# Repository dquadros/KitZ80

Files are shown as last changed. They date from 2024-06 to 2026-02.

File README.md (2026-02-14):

# Kit Z80

 Este projeto tem como partida uma solicitação de um dos leitores do meu blog ([https://dqsoft.blogspot.com](https://youtube.com/@DQSoft)). Ele possui um kit dos anos 80, o CEDM-80, e gostaria de um firmware novo para ele.
 
 Para escrever o firmware o primeiro passo é ter o hardware e aí está o projeto: construir um microcomputador compatível com o CEDM-80 (versão 1, para ser mais preciso). É um projeto de médio a longo prazo, ficarei muito feliz se o concluir até a ~~metade do ano atual (2024)~~ o final do primeiro trimestre de 2026.
 
 O projeto está sendo documentado no blog e no meu canal no Youtube ([https://youtube.com/@DQSoft](https://youtube.com/@DQSoft))
 
 ## Testes do Circuito de Reset (02/06/24)
 
 Em Circuito/TesteReset está o esquema do circuito montado para testar três opções para o Reset.
 
 ## Teste do Uso do 74HC373 como Latch/Porta de Saída (13/06/24)
 
 Em Circuito/Teste373 está o esquema do circuito montado para testar o uso do 74HC373 como porta de saída.
 
 Em Programas/TstBlink está o programa usado no teste.
  
 ## Teste da  RAM (24/08/24)
 
 Em Programas/MTest está o programa, que usa o gerador de números pseudo-aleatorios do Pitfall para testar a memória RAM!
 
 ## Teste Inicial do Display (14/04/25)
 
 Com a montagem da placa de I/O iniciada, é hora de testar o circuito de acionamento do display e validar o valor dos resistores de limitação de corrente.
 
 O programa de testes está em Programas/TstDisp.
 
 ## Teste Final do Display (14/02/25)
 
 Após mais uma longa pausa, a montagem do circuito do display está completa.
 
 O programa de testes está em Programas/TstDisp.

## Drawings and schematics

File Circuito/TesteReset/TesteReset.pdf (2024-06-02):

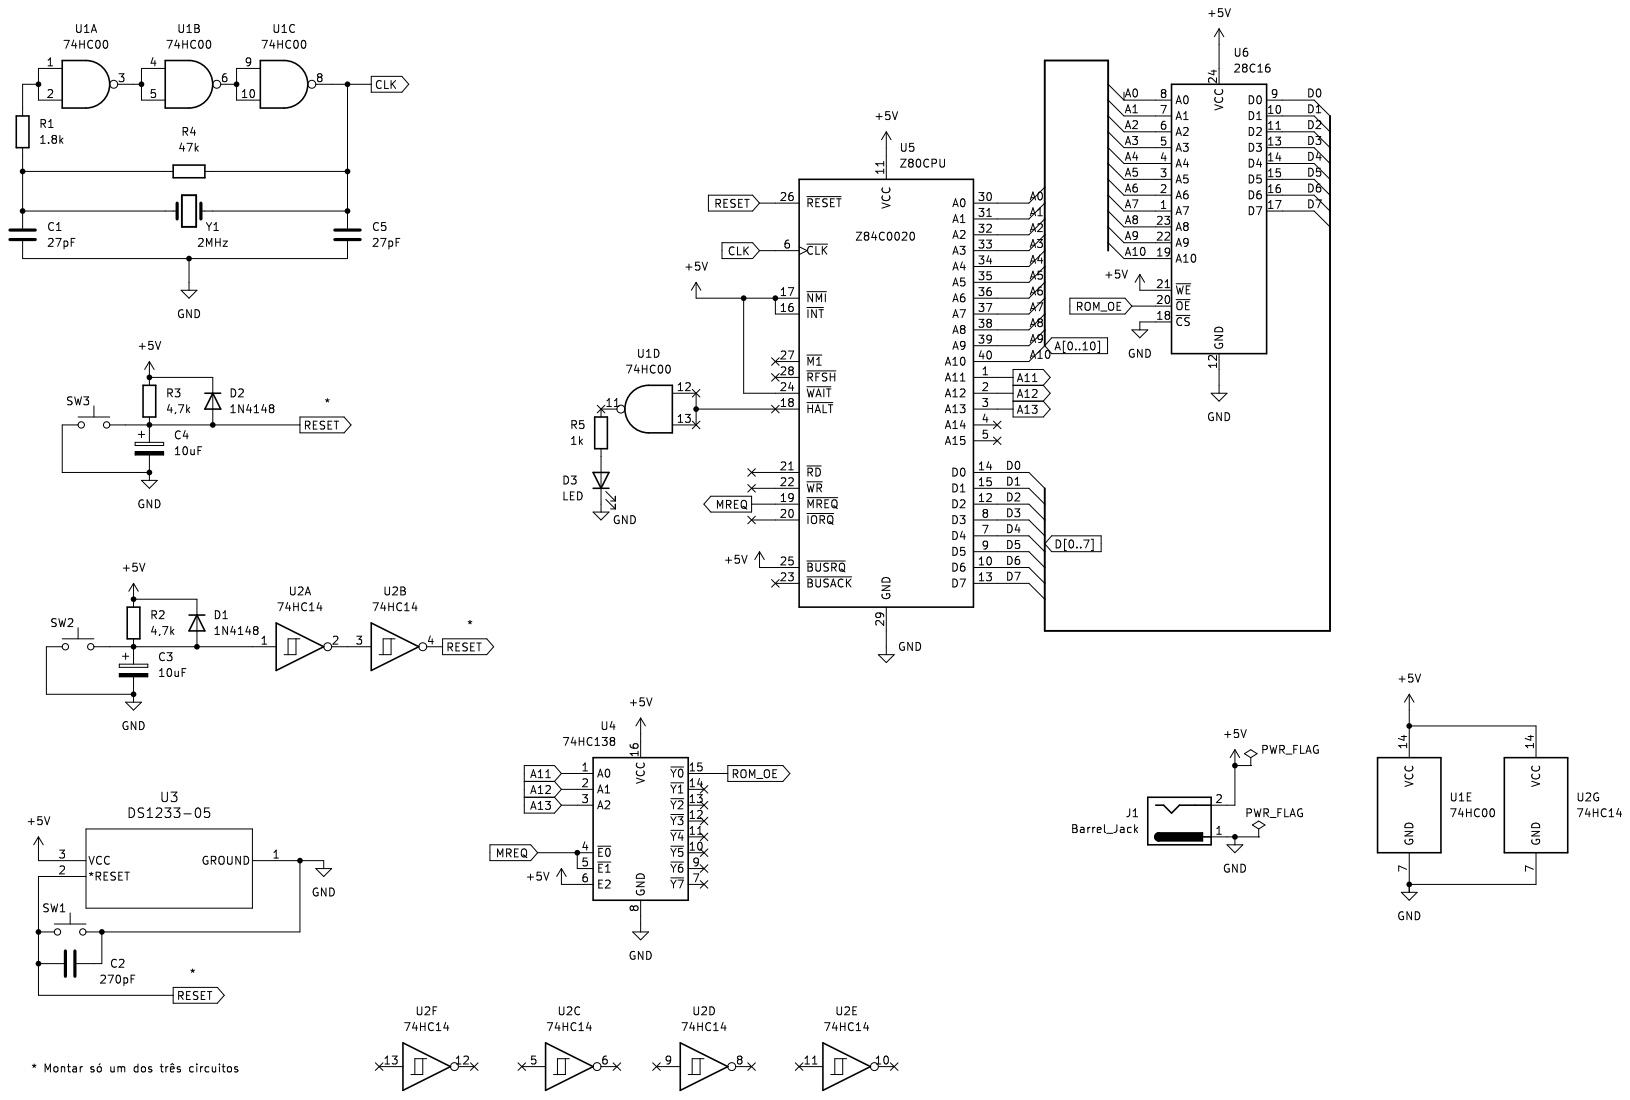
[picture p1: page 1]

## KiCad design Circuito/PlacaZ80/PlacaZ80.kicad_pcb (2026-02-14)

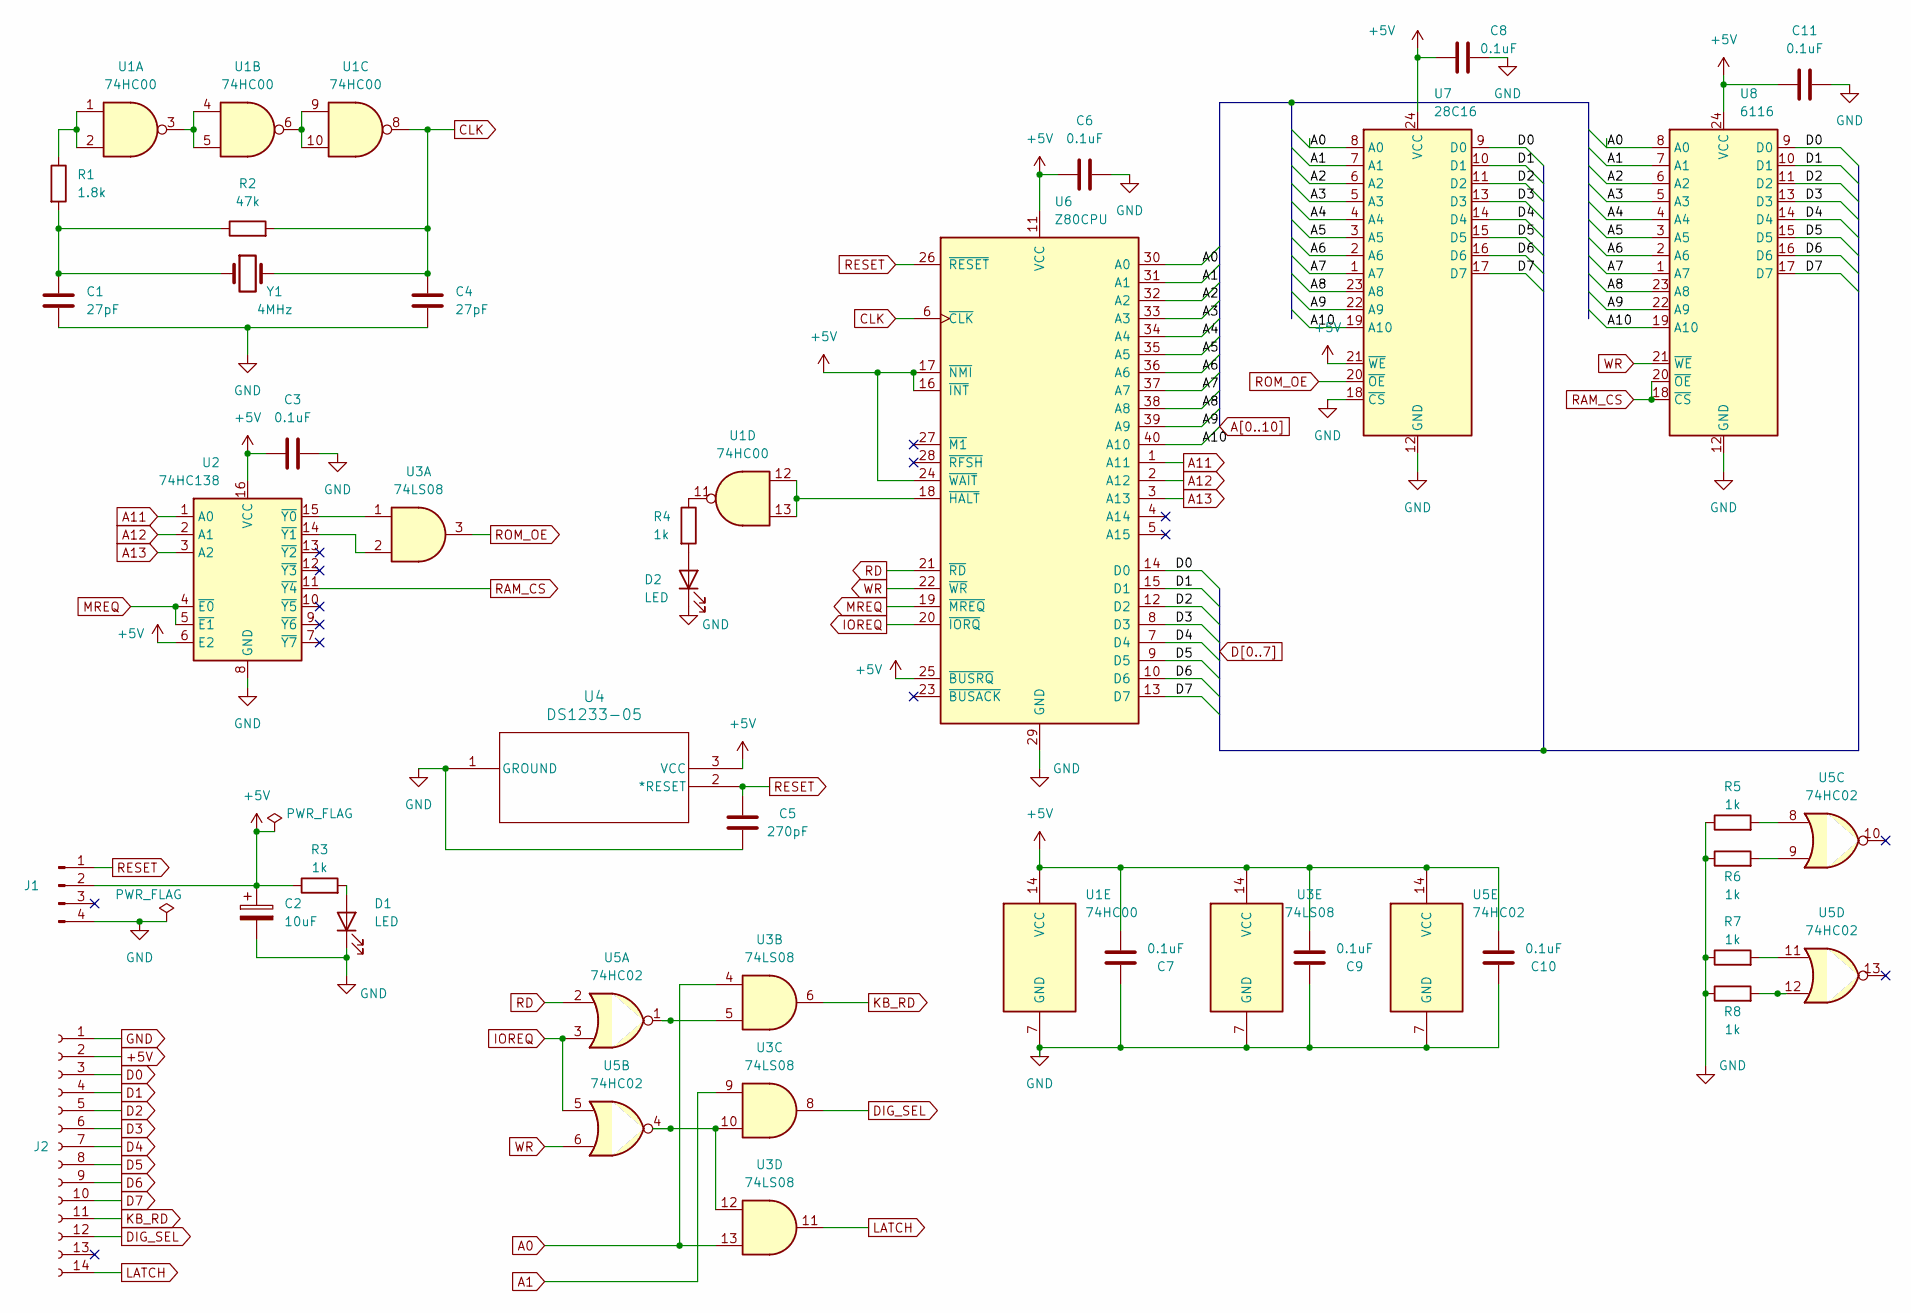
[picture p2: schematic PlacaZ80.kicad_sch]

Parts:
C1, C4: 27pF; C_Disc_D3.0mm_W2.0mm_P2.50mm
C2: 10uF; C_Radial_D5.0mm_H5.0mm_P2.00mm
C3, C6, C7, C8, C9, C10, C11: 0.1uF; C_Disc_D3.0mm_W2.0mm_P2.50mm
C5: 270pF; C_Disc_D3.0mm_W2.0mm_P2.50mm
D1, D2: LED; LED_D3.0mm
J1: Conn_01x04_Pin; PinHeader_1x04_P2.54mm_Horizontal
J2: Conn_01x14_Socket; PinSocket_1x14_P2.54mm_Horizontal
R1: 1.8k; R_Axial_DIN0207_L6.3mm_D2.5mm_P10.16mm_Horizontal
R2: 47k; R_Axial_DIN0207_L6.3mm_D2.5mm_P10.16mm_Horizontal
R3, R4, R5, R6, R7, R8: 1k; R_Axial_DIN0207_L6.3mm_D2.5mm_P10.16mm_Horizontal
U1: 74HC00; DIP-14_W7.62mm
U2: 74HC138; DIP-16_W7.62mm
U3: 74LS08; DIP-14_W7.62mm
U4: DS1233-05; 21-0250B_MXM
U5: 74HC02; DIP-14_W7.62mm
U6: Z80CPU; DIP-40_W15.24mm_Socket
U7: 28C16; DIP_Socket-24_W11.9_W12.7_W15.24_W17.78_W18.5_3M_224-1275-0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
U8: 6116; DIP-24_W15.24mm_Socket
Y1: 4MHz; Crystal_HC49-U_Vertical

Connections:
+5V: C2.1, C3.1, C6.1, C7.1, C8.1, C9.1, C10.1, C11.1, J1.2, J2.2, R3.1, U1.14 (VCC), U2.6 (E2), U2.16 (VCC), U3.14 (VCC), U4.3 (VCC), U5.14 (VCC), U6.11 (VCC), U6.16 (~INT), U6.17 (~NMI), U6.24 (~WAIT), U6.25 (~BUSRQ), U7.21 (~WE), U7.24 (VCC), U8.24 (VCC)
A0: U3.4, U3.13, U6.30 (A0), U7.8 (A0), U8.8 (A0)
A1: U3.9, U6.31 (A1), U7.7 (A1), U8.7 (A1)
A2: U6.32 (A2), U7.6 (A2), U8.6 (A2)
A3: U6.33 (A3), U7.5 (A3), U8.5 (A3)
A4: U6.34 (A4), U7.4 (A4), U8.4 (A4)
A5: U6.35 (A5), U7.3 (A5), U8.3 (A5)
A6: U6.36 (A6), U7.2 (A6), U8.2 (A6)
A7: U6.37 (A7), U7.1 (A7), U8.1 (A7)
A8: U6.38 (A8), U7.23 (A8), U8.23 (A8)
A9: U6.39 (A9), U7.22 (A9), U8.22 (A9)
A10: U6.40 (A10), U7.19 (A10), U8.19 (A10)
A11: U2.1 (A0), U6.1 (A11)
A12: U2.2 (A1), U6.2 (A12)
A13: U2.3 (A2), U6.3 (A13)
CLK: C4.1, R2.2, U1.8, U6.6 (~CLK), Y1.2
D0: J2.3, U6.14 (D0), U7.9 (D0), U8.9 (D0)
D1: J2.4, U6.15 (D1), U7.10 (D1), U8.10 (D1)
D2: J2.5, U6.12 (D2), U7.11 (D2), U8.11 (D2)
D3: J2.6, U6.8 (D3), U7.13 (D3), U8.13 (D3)
D4: J2.7, U6.7 (D4), U7.14 (D4), U8.14 (D4)
D5: J2.8, U6.9 (D5), U7.15 (D5), U8.15 (D5)
D6: J2.9, U6.10 (D6), U7.16 (D6), U8.16 (D6)
D7: J2.10, U6.13 (D7), U7.17 (D7), U8.17 (D7)
DIG_SEL: J2.12, U3.8
GND: C1.2, C2.2, C3.2, C4.2, C5.2, C6.2, C7.2, C8.2, C9.2, C10.2, C11.2, D1.1 (K), D2.1 (K), J1.4, J2.1, R5.1, R6.1, R7.1, R8.1, U1.7 (GND), U2.8 (GND), U3.7 (GND), U4.1 (GROUND), U5.7 (GND), U6.29 (GND), U7.12 (GND), U7.18 (~CS), U8.12 (GND)
IOREQ: U5.3, U5.5, U6.20 (~IORQ)
KB_RD: J2.11, U3.6
LATCH: J2.14, U3.11
MREQ: U2.4 (~E0), U2.5 (~E1), U6.19 (~MREQ)
unnamed: C1.1, R1.2, R2.1, Y1.1
unnamed: D1.2 (A), R3.2
unnamed: D2.2 (A), R4.2
unnamed: R1.1, U1.1, U1.2
unnamed: R4.1, U1.11
unnamed: R5.2, U5.8
unnamed: R6.2, U5.9
unnamed: R7.2, U5.11
unnamed: R8.2, U5.12
unnamed: U1.3, U1.4, U1.5
unnamed: U1.6, U1.9, U1.10
unnamed: U2.15 (~Y0), U3.1
unnamed: U2.14 (~Y1), U3.2
unnamed: U3.5, U5.1
unnamed: U3.10, U3.12, U5.4
unnamed: U1.12, U1.13, U6.18 (~HALT)
RAM_CS: U2.11 (~Y4), U8.18 (~CS), U8.20 (~OE)
RD: U5.2, U6.21 (~RD)
RESET: C5.1, J1.1, U4.2 (*RESET), U6.26 (~RESET)
ROM_OE: U3.3, U7.20 (~OE)
WR: U5.6, U6.22 (~WR), U8.21 (~WE)

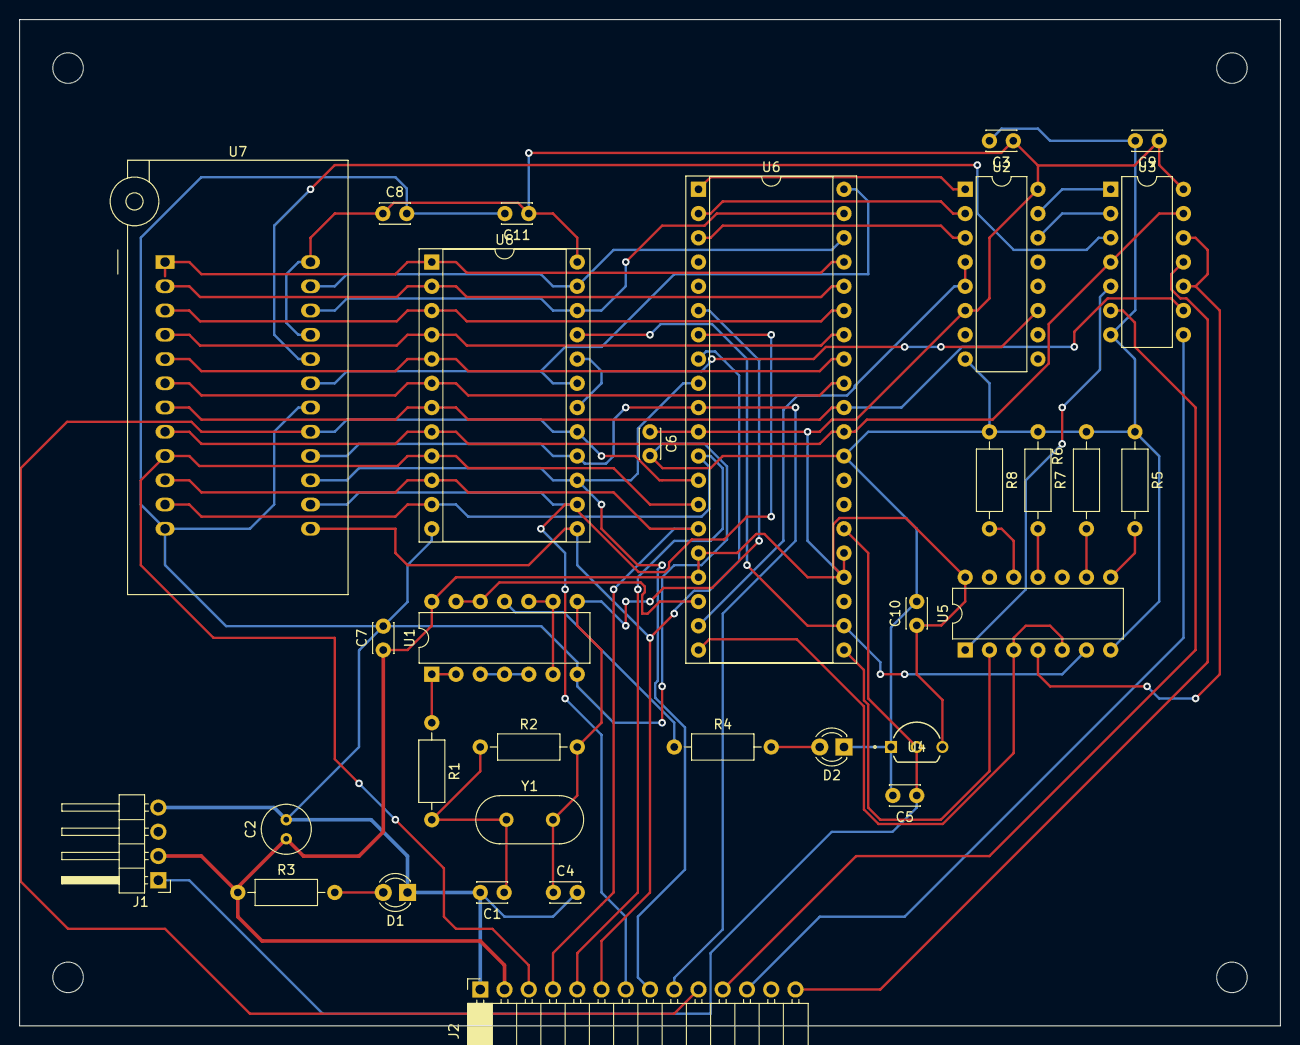
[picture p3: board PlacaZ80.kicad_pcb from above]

Board: 2 copper layers, 132.1 x 105.4 mm, 32 parts (0 on the bottom side), 51 nets.

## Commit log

2024-06-02 Inclusão do circuito de reset
    [TesteReset.kicad_sch]
2024-06-13 Acrescentado teste do 74HC373
    [Teste373.kicad_sch]
2024-08-26 Montagem e teste da placa CPU
    [PlacaZ80.kicad_pcb, PlacaZ80.kicad_sch, TesteReset.kicad_sch]
2026-02-14 Acréscimo da Placa de IO e o teste do Display
    [PlacaIO.kicad_pcb, PlacaIO.kicad_sch, PlacaZ80.kicad_pcb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]
